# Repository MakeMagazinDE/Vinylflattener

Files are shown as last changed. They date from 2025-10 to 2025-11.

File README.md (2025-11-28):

GitHub Logo

Maker Media GmbH

***

# Der Vinylflattener

### Bauanleitung für eine Bügelmaschine für Schallplatten

Manchmal sind Schallplatten durch falsche Lagerung oder mangelhafte Herstellung krumm geworden. Mit Wärme und Druck lässt sich die Platte retten und sie liefert wieder ungetrübten Musikgenuss. Kommerzielle Maschinen sind jedoch sehr teuer. In der Make 7/25 zeigen wir, wie man für wenige hundert Euro eine funktionale Bügelmaschine mit sehr präziser Temperatursteuerung selber bauen kann. Hier findet ihr 3D-Druck-Dateien für diverse Teile, den Code für den ESP32 und Anweisungen, wie eine kleine Steuerplatine verdrahtet werden muss.

 

# UPDATE - Zugentlastung

### Während man die Zugentlastung am PC-Netzteil pragmatisch mit Kabelbindern am Gehäuse fixiert, brauchen die beiden Heizplatten eine stabilere Lösung.

Hierfür habe ich eine Kabeldurchführung mit Klemmwirkung, bestehend aus zwei 3d gedruckten Teilen konstruiert, welche dann noch durch sogenannte Streckenverbinder im Rahmen oben und unten integriert wird. Eventuell muss man die Madenschrauben der Streckenverbinder etwas mit der Feile kürzen, bis sie nicht mehr nach oben aus der Konstruktion herausragen.
Die entsprechenden STL-Dateien dazu haben wir auch hier hinterlegt.

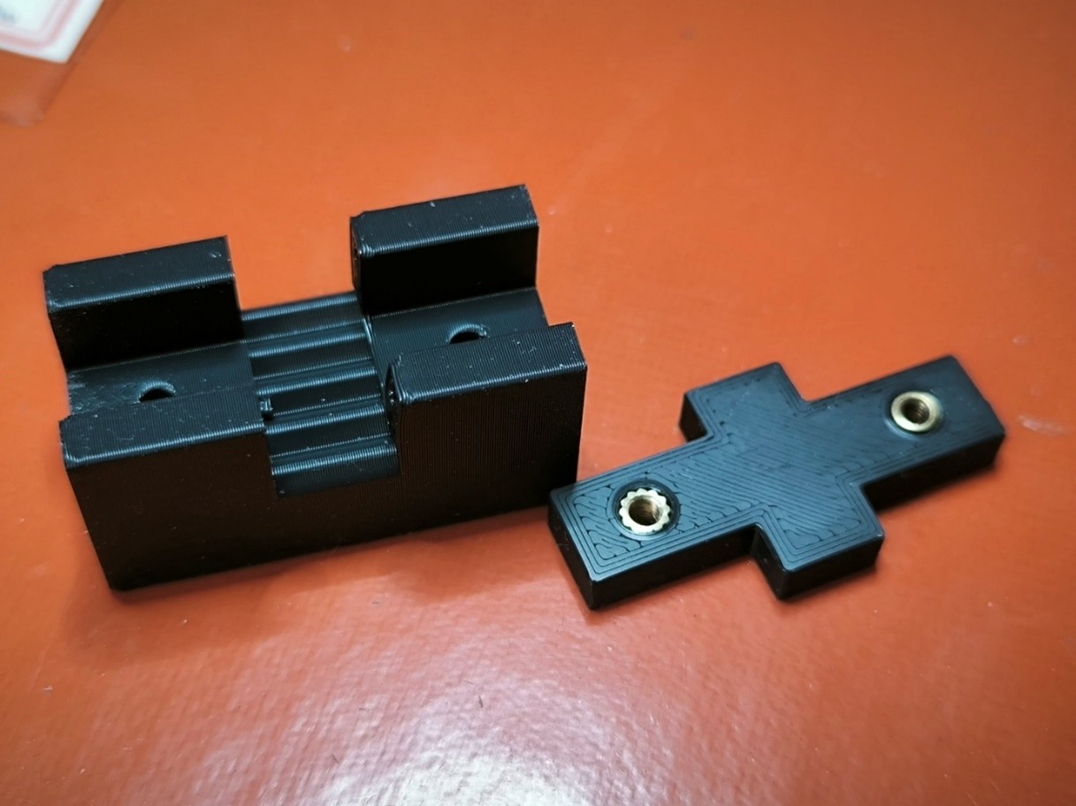
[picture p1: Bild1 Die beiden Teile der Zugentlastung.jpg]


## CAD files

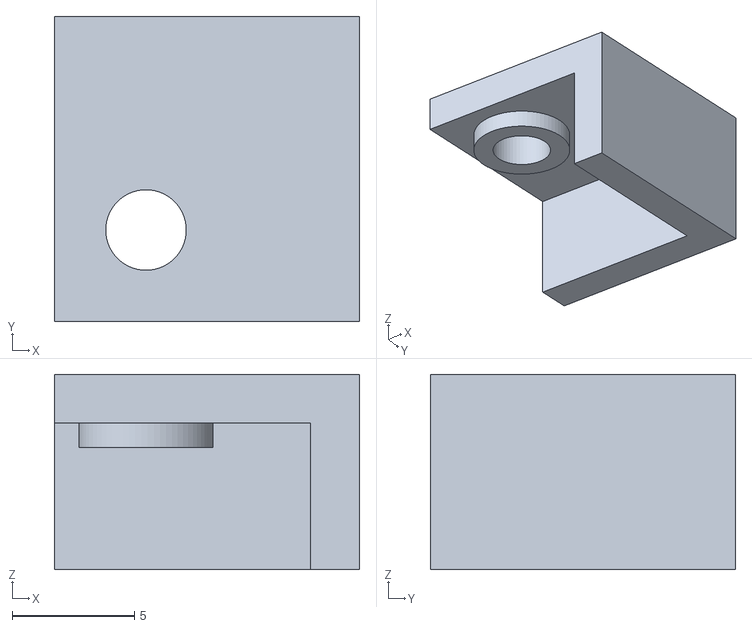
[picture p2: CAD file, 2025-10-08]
STL/VinylFlattener ESP Displayklammer v2.stl
12.5 x 12.5 x 8.00

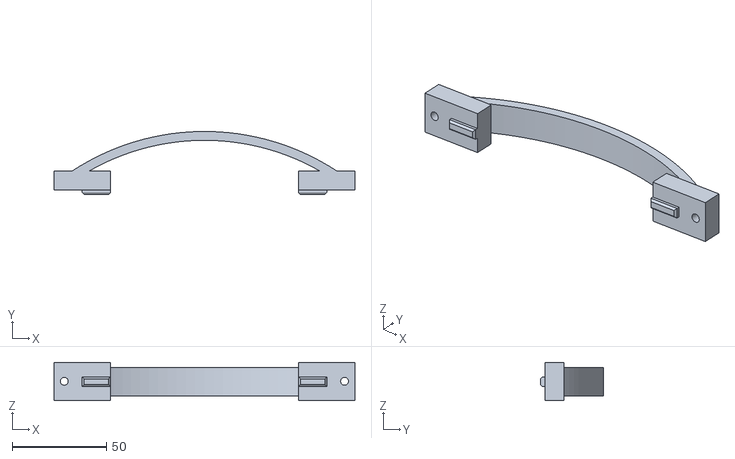
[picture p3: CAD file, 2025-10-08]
STL/Vinylflattener Griff_ASA v1.stl
160.0 x 33.5 x 20.2

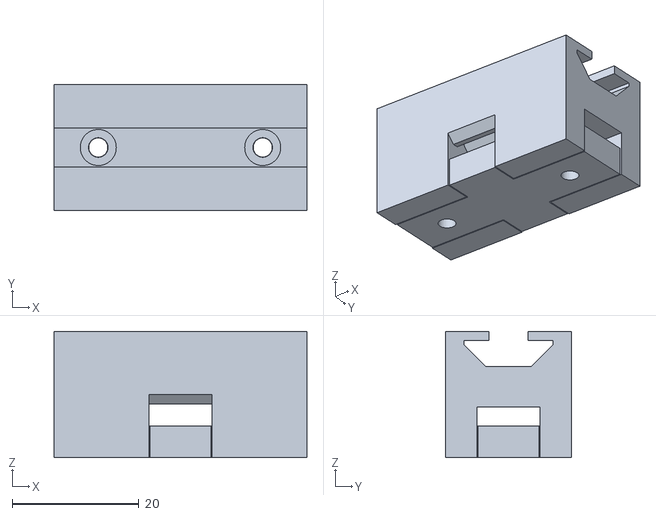
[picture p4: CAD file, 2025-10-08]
STL/Vinylflattener Kabeldurchführung v4.stl
40.0 x 20.0 x 20.0

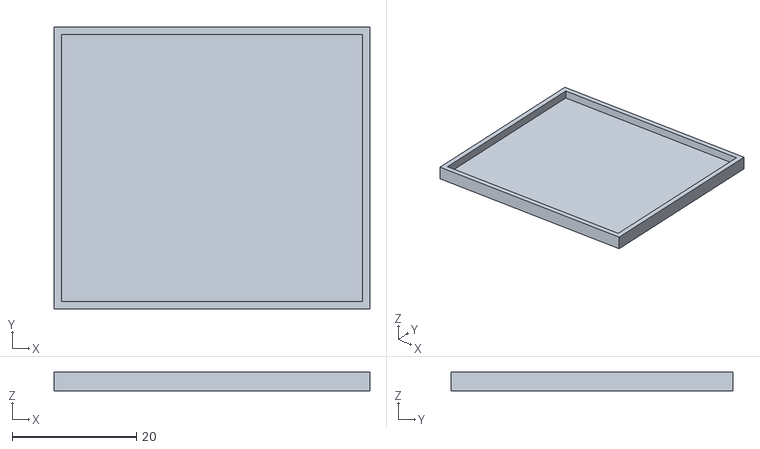
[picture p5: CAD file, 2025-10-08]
STL/Vinylflattener Platinenboden TPU v1.stl
50.9 x 45.4 x 3.00

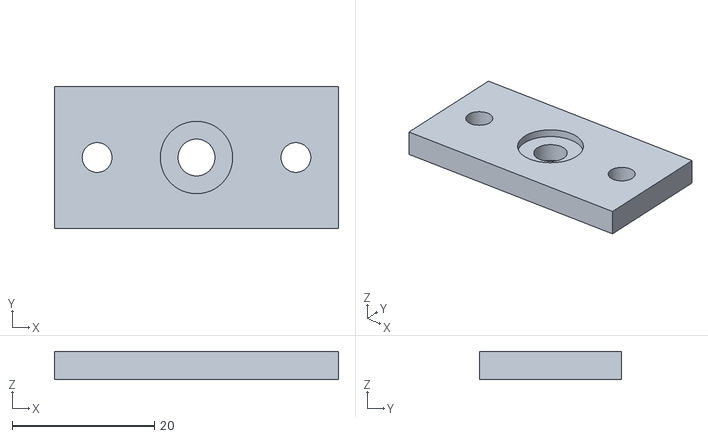
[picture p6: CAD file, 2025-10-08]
STL/Vinylflattener seitliche Scharnierhalterung v1.stl
40.0 x 20.0 x 4.00

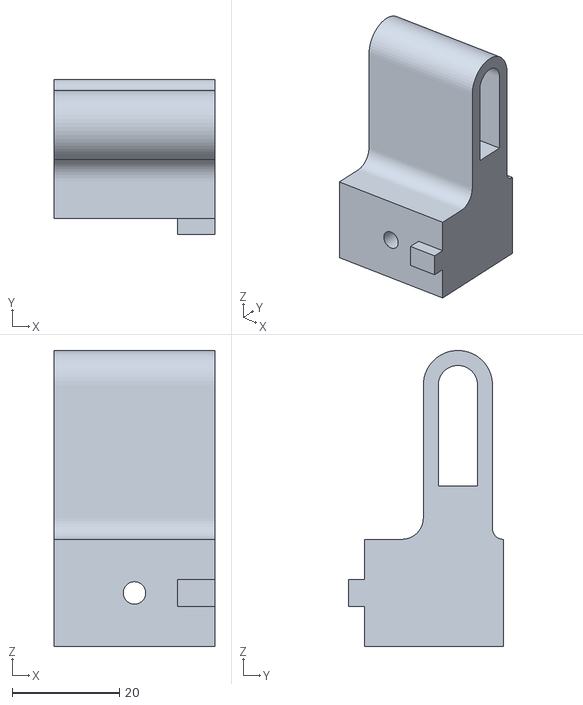
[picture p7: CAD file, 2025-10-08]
STL/Vinylflattener Scharnier unten.stl
30.0 x 29.0 x 55.2

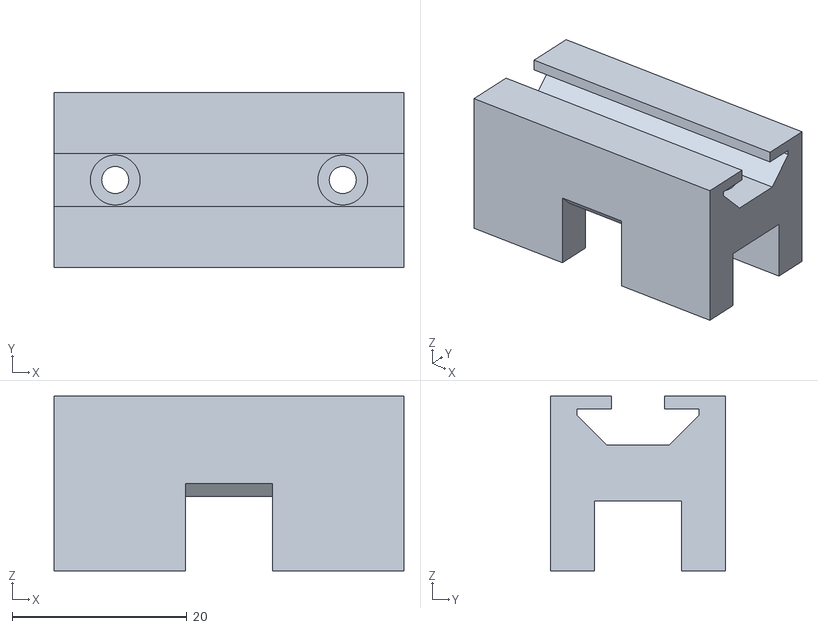
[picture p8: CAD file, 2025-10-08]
STL/Vinylflattener Kabeldurchführung v4 Oberteil.stl
40.0 x 20.0 x 20.0

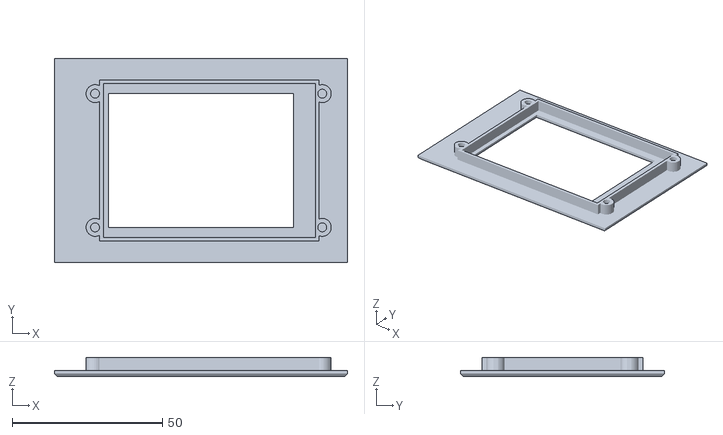
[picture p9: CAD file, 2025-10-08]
STL/VinylFlattener Einbaurahmen 2.8 Touch v4.stl
97.5 x 68.0 x 6.40

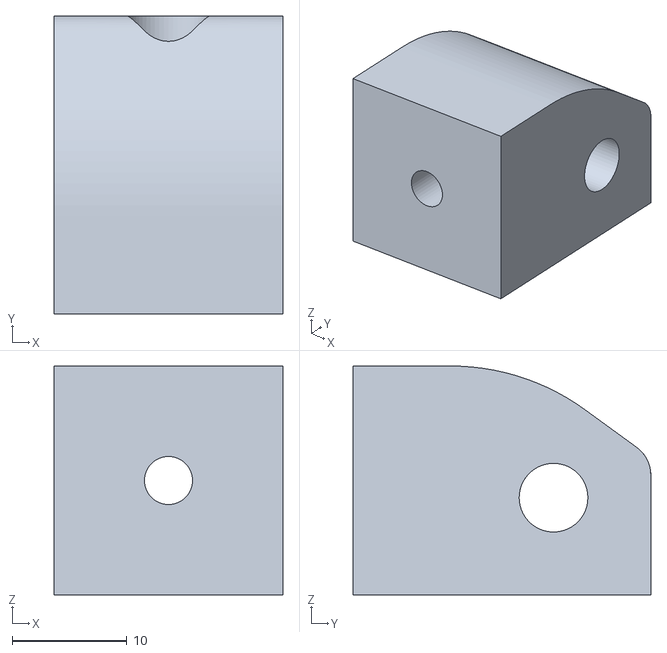
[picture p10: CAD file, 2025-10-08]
STL/Vinyflattener Scharnier oben v1.stl
20.0 x 26.0 x 20.0

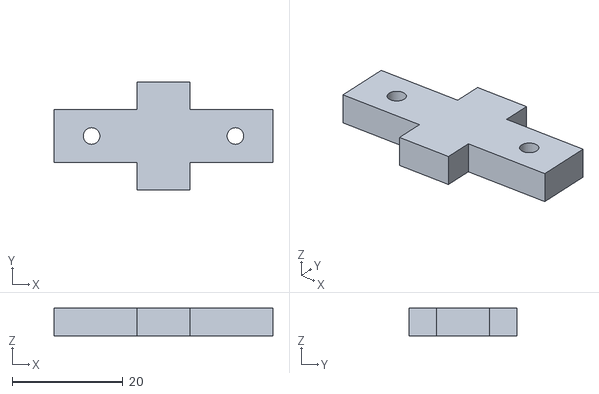
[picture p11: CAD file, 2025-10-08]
STL/Vinylflattener Kabeldurchführung v4 Unterteil.stl
39.6 x 19.6 x 5.00

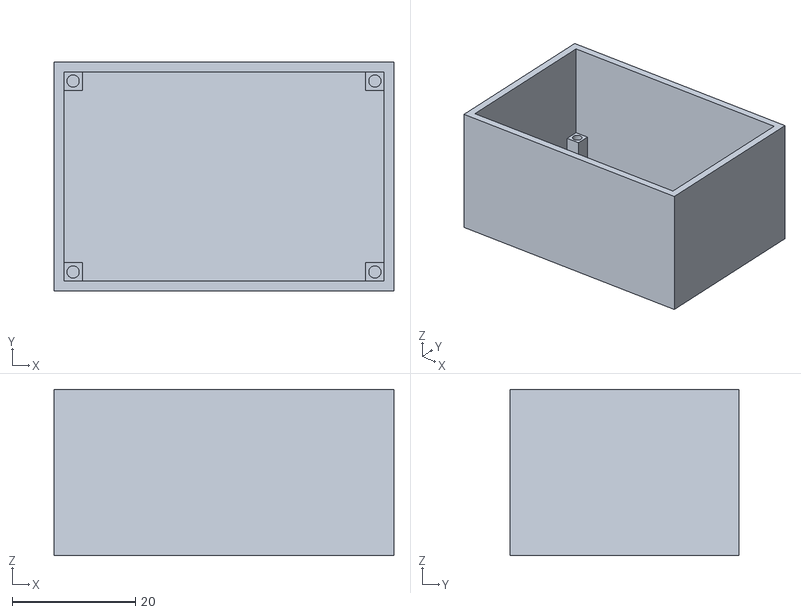
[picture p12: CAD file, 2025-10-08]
STL/Vinyflattener ESP Gehäuse v2 TPU.stl
55.2 x 37.2 x 27.0

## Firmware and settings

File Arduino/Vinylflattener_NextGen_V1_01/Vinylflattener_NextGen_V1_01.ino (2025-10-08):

/*
#diy #Vinylflattener, NextGen 
Version 1.01, 18.07.2025
@vincent05.bsky.social

Cleanup & Debug Ooption added

V1.01: MCP added

*/

//Libraries

#include <Arduino.h>
#include <Wire.h>
#include <FT6X36.h>
#include <TFT_eSPI.h>
#include <TaskScheduler.h>  // TaskScheduler Library

// uncomment for debug output
//#define DEBUG
//#define DEBUGSENSOR
//#define DEBUGMCP

// Heizungsregelung

#include <AutoPID.h>
#include <DallasTemperature.h>
#include <OneWire.h>

#define GFXFF 1
#define CF_RT24 &Roboto_Thin_24
#define CF_FSB12 &FreeSansBold12pt7b


//Temperaturregelung
#define TEMP_READ_DELAY 1000  //can only read digital temp sensor every ~750ms

//pid settings fuer Relaisbetieb
#define PULSEWIDTH 200   
//#define KP .12
//#define KI .0003
//#define KD 3
#define KP 0.09
#define KI 0.0002
#define KD 1.8


//GPIO Pins, die Pins fuer das TFT Display sind in der Datei User_Setup.h definiert

#define TEMP_SENSOR1_PIN 16
#define TEMP_SENSOR2_PIN 17
#define RELAIS1 5
#define RELAIS2 19
#define T_RST 27  // Touch Controller Reset Pin
#define T_INT 26  // Touch Controller Interrupt Pin

FT6X36 ts(&Wire, T_INT);  //Touch Controller Interruptpin (CTP_INT)
TFT_eSPI tft = TFT_eSPI();
// Button-Positionen und Größen
#define BUTTON_START_X 140
#define BUTTON_START_Y 200
#define BUTTON_START_W 100
#define BUTTON_START_H 50

#define BUTTON_STOP_X 20
#define BUTTON_STOP_Y 200
#define BUTTON_STOP_W 100
#define BUTTON_STOP_H 50

#define NAV_UP_X 300
#define NAV_UP_Y 40
#define NAV_DOWN_X 300
#define NAV_DOWN_Y 200

// Navigation button touch areas
#define NAV_UP_TOUCH_X 280
#define NAV_UP_TOUCH_Y 20
#define NAV_UP_TOUCH_W 40
#define NAV_UP_TOUCH_H 40

#define NAV_DOWN_TOUCH_X 280
#define NAV_DOWN_TOUCH_Y 180
#define NAV_DOWN_TOUCH_W 40
#define NAV_DOWN_TOUCH_H 40

// Slider-Bereiche
#define SLIDER_TEMP_X 20
#define SLIDER_TEMP_Y 80
#define SLIDER_TEMP_W 280
#define SLIDER_TEMP_H 20
#define SLIDER_TIME_X 20
#define SLIDER_TIME_Y 150
#define SLIDER_TIME_W 280
#define SLIDER_TIME_H 20

// Variablen Temperaturregelung
double targetTemperature = 55;    // Solltemperatur Startwert
double currentTemperature1 = 21;  // Isttemperatur 1
double currentTemperature2 = 22;  // Isttemperatur 2

double temperature1;
double temperature2;
double setPoint;
double tempThreshold = 0.8;  //Schwellwert für Abbruch bei Überhitzung (MCP Watchdog)

bool RelayControl1, RelayControl2;
double changeTemp1;
double changeTemp2;
double RampTime = 300;  // Zeitintervall für einen Durchlauf der Funktion TemperatureRamp (kleiner => genauer)
double RampUpdate = 0;  //Variable in der Funktion TemperatureRamp
double currentSetpoint = 10; //Variable in der Funktion TemperatureRamp
double powerupTemperature = 0;  //Variable in der Funktion TemperatureRamp
double powerUpFactor = 9;  // Zieltemperatur - powerUpFactor ergibt den Wert, bis zu dem das System ungeregelt aufheizt
double rampRate = 0.8;  //Variable in der Funktion TemperatureRamp, größer bedeutet schnelleres Aufheizen (default 0.5)
int pidTimeStep = 50;  // die Zeit, wie oft eine Neuberechnung von autoPID durchgeführt wird, sollte <= PULSEWIDTH sein

unsigned long lastTempUpdate1;  //tracks clock time of last temp1 update
unsigned long lastTempUpdate2;  //tracks clock time of last temp2 update
unsigned long Time;

// alle anderen Variablen
int timeSetting = 240;     // Zeiteinstellung (in Minuten), (Startwert)
int lastTargetTemp = -1;   // Zum Überprüfen, ob die Temperatur geändert wurde
int lastTimeSetting = -1;  // Zum Überprüfen, ob die Zeit geändert wurde
int countdownSeconds = 0;  // Anzeige basiert auf dieser Sekunde
int errorcount = 0;        // MCP Zähler
int stopcount = 0;         // MCP Zähler

// Slider-Bereiche definieren
const int tempMin = 48;   //Minimalwert Temperaturslider
const int tempMax = 70;   //Maximalwert Temperaturslider
const int timeMin = 1;    //Minimalwert Zeitslider
const int timeMax = 360;  //Maximalwert Zeitslider

// Letzte Slider-Positionen speichern (um alte Marker zu löschen)
int lastTempSliderPos = -1;
int lastTimeSliderPos = -1;

int old_x = 0;
int old_y = 0;


// Seitenwechsel
int currentPage = 1;
bool screenChanged = true;

// Timer Variablen
unsigned long timerStartMillis = 0;  // Speichert den Startzeitpunkt des Timers
unsigned long remainingMillis = 0;   // Speichert die verbleibende Zeit in Millisekunden
unsigned long lastUpdate = 0;        // Letzter Zeitpunkt, wo der Countdown aktualisiert wurde

// Timer läuft?
bool timerRunning = false;  // Flag, das angibt, ob der Timer läuft
bool timerExpired = false;  // Flag, das anzeigt, dass der Timer abgelaufen ist

//Laufzeitprüfung

unsigned long startTime = 0;
unsigned long endTime = 0;
unsigned long duration = 0;

//Temperatursteuerung initialisieren

OneWire oneWire1(TEMP_SENSOR1_PIN);
OneWire oneWire2(TEMP_SENSOR2_PIN);
DallasTemperature temperatureSensor1(&oneWire1);
DallasTemperature temperatureSensor2(&oneWire2);



//input/output variables passed by reference, so they are updated automatically
AutoPIDRelay myPID1(&temperature1, &setPoint, &RelayControl1, PULSEWIDTH, KP, KI, KD);
AutoPIDRelay myPID2(&temperature2, &setPoint, &RelayControl2, PULSEWIDTH, KP, KI, KD);

Scheduler runner;

//Funktionen zu den Tasks deklarieren
void updateRemainingMillis();   //Zeitbasis
void touchTaskCallback();       // Task für die Touch-Abfrage erstellen
void temperatureUpdateTask1();  //Abfrage Sensor 1
void temperatureUpdateTask2();  //Abfrage Sensor 2
void screenUpdateTask();        //Bildschirmaktualisierung während der Timer läuft
void countdownTickTask();       //Zeitanzeige mit eigener Zeitberechnung für den Timer
void masterControlProgram();    //Sicherheitstask zur Überwachung von max. Temp und Sensor Output

//Tasks
Task timerCalcTask(250, TASK_FOREVER, &updateRemainingMillis);
Task touchTask(5, TASK_FOREVER, &touchTaskCallback);
Task taskTempUpdate1(TEMP_READ_DELAY, TASK_FOREVER, &temperatureUpdateTask1);
Task taskTempUpdate2(TEMP_READ_DELAY, TASK_FOREVER, &temperatureUpdateTask2);
Task screenTask(20, TASK_FOREVER, &screenUpdateTask);
Task countdownTick(20, TASK_FOREVER, &countdownTickTask);
Task mcpTask(100, TASK_FOREVER, &masterControlProgram);

void countdownTickTask() {
  static int lastDisplayedSeconds = -1;

  if (timerRunning) {
    unsigned long elapsed = millis() - timerStartMillis;
    int newCountdownSeconds = (timeSetting * 60) - (elapsed / 1000);

    // Timerende prüfen
    if (newCountdownSeconds <= 0) {
      countdownSeconds = 0;
      timerRunning = false;
      timerExpired = true;
      stopAll();
    } else {
      countdownSeconds = newCountdownSeconds;
    }

    // Nur anzeigen, wenn sich die Sekunde geändert hat
    if (countdownSeconds != lastDisplayedSeconds) {
      lastDisplayedSeconds = countdownSeconds;
      updateCountdown();  // Anzeige aktualisieren
    }
  }
}


void updateRemainingMillis() {
  if (timerRunning && !timerExpired) {
    unsigned long timerMillis = millis();
    remainingMillis = (timeSetting * 60 * 1000) - (timerMillis - timerStartMillis);

    if ((remainingMillis <= 0) || (remainingMillis > (timeSetting * 60 * 1000))) {
      remainingMillis = 0;
      timerRunning = false;
      timerExpired = true;
#ifdef DEBUG
      Serial.println("Timer abgelaufen!");
#endif
      stopAll();
    }
  }
}

void handleNavigation(TPoint p) {
  int oldPage = currentPage;

  if (p.x > NAV_UP_TOUCH_X && p.x < NAV_UP_TOUCH_X + NAV_UP_TOUCH_W && p.y > NAV_UP_TOUCH_Y && p.y < NAV_UP_TOUCH_Y + NAV_UP_TOUCH_H) {
    currentPage++;
    if (currentPage > 3) currentPage = 1;
  } else if (p.x > NAV_DOWN_TOUCH_X && p.x < NAV_DOWN_TOUCH_X + NAV_DOWN_TOUCH_W && p.y > NAV_DOWN_TOUCH_Y && p.y < NAV_DOWN_TOUCH_Y + NAV_DOWN_TOUCH_H) {
    currentPage--;
    if (currentPage < 1) currentPage = 3;
  }

  if (oldPage != currentPage) {
    screenChanged = true;
#ifdef DEBUG
    Serial.print("Switching to page: ");
    Serial.println(currentPage);
#endif
  }
}

void processTouch(TPoint p, TEvent e) {

  // if ((e == TEvent::Tap) || (e == TEvent::TouchMove)) {
  if (e != TEvent::Tap && e != TEvent::DragStart && e != TEvent::DragMove && e != TEvent::DragEnd)
    return;

  // Umrechnen der X- und Y-Koordinaten
  int new_x = 320 - p.y;  // 320 - Y_Touch
  int new_y = p.x;        // X_Touch

  p.x = new_x;
  p.y = new_y;
  if ((old_x == new_x) && (old_y == new_y))
    return;  //deBouncing durch Abbruch bei identischen Werten für x und Y

  old_x = new_x;
  old_y = new_y;
#ifdef DEBUG
  Serial.print("Tap detected at X: ");
  Serial.print(p.x);
  Serial.print(" Y: ");
  Serial.println(p.y);
#endif
  switch (currentPage) {
    case 1:
      if (p.x > BUTTON_START_X && p.x < BUTTON_START_X + BUTTON_START_W && p.y > BUTTON_START_Y && p.y < BUTTON_START_Y + BUTTON_START_H) {
#ifdef DEBUG
        Serial.println(F("Start Button pressed"));
#endif
        if (!timerRunning) {
          timerRunning = true;
          timerStartMillis = millis();
          remainingMillis = timeSetting * 60 * 1000;
          countdownSeconds = timeSetting * 60;  // ← neue Anzeige-Zeit in Sekunden
          timerExpired = false;
        }
      }

      if (p.x > BUTTON_STOP_X && p.x < BUTTON_STOP_X + BUTTON_STOP_W && p.y > BUTTON_STOP_Y && p.y < BUTTON_STOP_Y + BUTTON_STOP_H) {
#ifdef DEBUG
        Serial.println(F("Stop Button pressed"));
#endif
        stopAll();
      }
      break;
    case 2:
#ifdef DEBUG
      Serial.println(F("Touchscreen 2"));
      Serial.print(p.x);
      Serial.print(" Y: ");
      Serial.println(p.y);
#endif
      // Slider-Berührung
      if (p.x > SLIDER_TEMP_X && p.x < SLIDER_TEMP_X + SLIDER_TEMP_W && p.y > SLIDER_TEMP_Y && p.y < SLIDER_TEMP_Y + SLIDER_TEMP_H) {
        targetTemperature = map(p.x, SLIDER_TEMP_X, SLIDER_TEMP_X + SLIDER_TEMP_W, tempMin, tempMax);
        drawSlider(SLIDER_TEMP_X, SLIDER_TEMP_Y, SLIDER_TEMP_W, targetTemperature, tempMin, tempMax, TFT_RED, lastTempSliderPos);
#ifdef DEBUG
        Serial.print(F("Temperature set to: "));
        Serial.println(targetTemperature);
#endif
      }
      if (p.x > SLIDER_TIME_X && p.x < SLIDER_TIME_X + SLIDER_TIME_W && p.y > SLIDER_TIME_Y && p.y < SLIDER_TIME_Y + SLIDER_TIME_H) {
        timeSetting = map(p.x, SLIDER_TIME_X, SLIDER_TIME_X + SLIDER_TIME_W, timeMin, timeMax);
        drawSlider(SLIDER_TIME_X, SLIDER_TIME_Y, SLIDER_TIME_W, timeSetting, timeMin, timeMax, TFT_BLUE, lastTimeSliderPos);
#ifdef DEBUG
        Serial.print(F("Time set to: "));
        Serial.println(timeSetting);
#endif
      }
      break;
    case 3:
      //Touchscreen 3;
#ifdef DEBUG
      Serial.println(F("Touchscreen 3"));
      Serial.print(p.x);
      Serial.print(" Y: ");
      Serial.println(p.y);
#endif
      break;
  }
  handleNavigation(p);

  //}
}


void updateScreen() {
  if (!screenChanged) return;

  tft.fillScreen(TFT_BLACK);  // Clear screen
  //tft.setCursor(50, 50);
  //tft.setTextColor(TFT_WHITE);

  switch (currentPage) {
    case 1:
      //tft.print("Screen 1");
      setupScreen1();
      break;
    case 2:
      //tft.print("Screen 2");
      setupScreen2();
      break;
    case 3:
      //tft.print("Screen 3");
      setupScreen3();
      break;
  }

  drawNavigationArrows();
  screenChanged = false;
}

void drawNavigationArrows() {
  // Oben (nächste Seite)
  tft.fillTriangle(NAV_UP_X, NAV_UP_Y, NAV_UP_X - 10, NAV_UP_Y - 20, NAV_UP_X - 20, NAV_UP_Y, TFT_WHITE);

  // Unten (vorherige Seite)
  tft.fillTriangle(NAV_DOWN_X, NAV_DOWN_Y, NAV_DOWN_X - 10, NAV_DOWN_Y + 20, NAV_DOWN_X - 20, NAV_DOWN_Y, TFT_WHITE);
}

void drawStartStopButtons() {
  // Start-Button (rechts unten)
  tft.fillRect(BUTTON_START_X, BUTTON_START_Y, BUTTON_START_W, BUTTON_START_H, TFT_GREEN);
  tft.setTextColor(TFT_WHITE);
  tft.setCursor(BUTTON_START_X + 14, BUTTON_START_Y + 28);
  tft.print("START");

  // Stop-Button (links unten)
  tft.fillRect(BUTTON_STOP_X, BUTTON_STOP_Y, BUTTON_STOP_W, BUTTON_STOP_H, TFT_RED);
  tft.setTextColor(TFT_WHITE);
  tft.setCursor(BUTTON_STOP_X + 16, BUTTON_STOP_Y + 28);
  tft.print("STOP");
}

void setupScreen1() {

  // Fülle den Bildschirm mit Hintergrundfarbe
  tft.fillScreen(TFT_BLACK);

  // Zeichne Textzeilen
  tft.setTextColor(TFT_WHITE, TFT_BLACK);
  tft.setFreeFont(CF_RT24);  // Setzt den Font auf Roboto Thin 24

  tft.setCursor(20, 20);
  tft.print("Ist-Temp 1: ");
  //tft.print(currentTemperature1);
  tft.print(temperature1);
  tft.print(" C");

  tft.setCursor(20, 50);
  tft.print("Ist-Temp 2: ");
  //tft.print(currentTemperature2);
  tft.print(temperature2);
  tft.print(" C");

  tft.setCursor(20, 80);
  tft.print("Soll-Temp:  ");
  tft.print(targetTemperature);
  tft.print(" C");

  if (!timerRunning) {
    // } else {
    tft.setCursor(20, 110);
    tft.print("Restzeit:   ");
    tft.print(timeSetting);
    tft.print(":00");
    tft.print(" Min");
  }

  // Start- und Stop-Buttons zeichnen
  drawStartStopButtons();
  drawNavigationArrows();
}

void setupScreen2() {
  // Seite 2: Solltemperatur und Zeit einstellen
  tft.fillScreen(TFT_BLACK);
  tft.setFreeFont(CF_RT24);  // Setzt den Font auf Roboto Thin 24

  tft.setCursor(50, 50);
  tft.setTextColor(TFT_WHITE);
  tft.print("Soll-Temp: ");
  tft.print(targetTemperature);
  tft.print(" C");

  tft.setCursor(50, 120);
  tft.setTextColor(TFT_WHITE);
  tft.print("Zeit: ");
  tft.print(timeSetting);
  tft.print(" Min");

  // Slider für Temperatur zeichnen
  drawSlider(20, 80, 280, targetTemperature, tempMin, tempMax, TFT_RED, lastTempSliderPos);

  // Slider für Zeit zeichnen
  drawSlider(20, 150, 280, timeSetting, timeMin, timeMax, TFT_BLUE, lastTimeSliderPos);



  drawNavigationArrows();
}
// Slider zeichnen
void drawSlider(int x, int y, int w, int value, int minVal, int maxVal, uint16_t color, int &lastPos) {
  tft.drawRect(x, y, w, 10, TFT_WHITE);

  int sliderPos = map(value, minVal, maxVal, x, x + w);

  if (lastPos != -1 && lastPos != sliderPos) {
    tft.fillRect(lastPos - 5, y - 5, 10, 20, TFT_BLACK);
  }

  tft.fillRect(sliderPos - 5, y - 5, 10, 20, color);

  lastPos = sliderPos;
}

void setupScreen3() {

  // Fülle den Bildschirm mit Hintergrundfarbe
  tft.fillScreen(TFT_DARKGREEN);
  tft.setTextColor(TFT_LIGHTGREY);
  tft.setFreeFont(CF_RT24);  // Setzt den Font auf Roboto Thin 24

  tft.setCursor(30, 50);
  //tft.setTextColor(TFT_WHITE);
  tft.print("#diy #Vinylflattener");
  tft.setCursor(30, 90);
  tft.print("NextGen V1.0, 2025");
  tft.setCursor(30, 130);
  tft.print("contact:");
  tft.setCursor(30, 170);
  tft.print("@vincent05.bsky.social");

  drawNavigationArrows();  // Zeichne Navigationspfeile
}

void screenUpdateTask() {

  if (currentPage == 1) {
    unsigned long updateMillis = millis();
    if (updateMillis - lastUpdate >= 500) {
      if ((abs(changeTemp1) >= 0.06) || (abs(changeTemp2) >= 0.06)) {
        tft.fillRect(150, 0, 120, 24, TFT_BLACK);
        tft.setCursor(20, 20);
        tft.setTextColor(TFT_WHITE);
        tft.print("Ist-Temp 1: ");
        //tft.print(currentTemperature1); //Darstellung der Sensordaten
        tft.print(temperature1);  //fehlerbereinigte Darstellung
        tft.print(" C");

        tft.fillRect(150, 30, 120, 24, TFT_BLACK);
        tft.setCursor(20, 50);
        tft.setTextColor(TFT_WHITE);
        tft.print("Ist-Temp 2: ");
        //tft.print(currentTemperature2); //fehlerbereinigte Darstellung
        tft.print(temperature2);  //fehlerbereinigte Darstellung
        tft.print(" C");
      }

      lastUpdate = updateMillis;
    }
  } else if (currentPage == 2) {
    updateControlPage();
  }
}
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
void loop() {

  endTime = millis();

  runner.execute();  // Scheduler steuert die Tasks

  //Temperaturregelung
  Time = millis();
  if (timerRunning && !timerExpired) {
    TemperatureRamp();

    myPID1.run();  //call every loop, updates automatically at certain time interval
    myPID2.run();  //call every loop, updates automatically at certain time interval
  }
  if (RelayControl1 != 0) {
    digitalWrite(RELAIS1, HIGH);
  } else {
    digitalWrite(RELAIS1, LOW);
  }
  if (RelayControl2 != 0) {
    digitalWrite(RELAIS2, HIGH);
  } else {
    digitalWrite(RELAIS2, LOW);
  }

  updateScreen();  // Bildschirm Update falls notwendig

  duration = endTime - startTime;
  if (duration > 1) {
#ifdef DEBUG
    Serial.print("Laufzeit: ");
    Serial.println(duration);
#endif
  }
  startTime = millis();
}

void touchTaskCallback() {
  ts.loop();  // Touch-Abfrage ausführen // Hier kannst du weitere Aktionen ausführen, wenn ein Touch-Event erkannt wird
  if (ts.touched()) {
    //  unsigned char result = ts.touched();
    unsigned char result = ts.getCachedTouches();

#ifdef DEBUG
    Serial.println("Touch detected");
    Serial.println(result);
#endif
  }
}

void temperatureUpdateTask1() {

  if ((millis() - lastTempUpdate1) > TEMP_READ_DELAY) {
    temperature1 = temperatureSensor1.getTempCByIndex(0);  //get temp reading
    lastTempUpdate1 = millis();
    temperatureSensor1.requestTemperatures();  //request reading for next time
    changeTemp1 = currentTemperature1 - temperature1;
    currentTemperature1 = temperature1;
    if (currentTemperature1 < 0) {  //errorhandling, wenn der Sensor -127 zurück gibt
      temperature1 = targetTemperature;
#ifdef DEBUGSENSOR
      Serial.println("error reading Temperature Sensor 1");
#endif
    }
  }
}

void temperatureUpdateTask2() {
  if ((millis() - lastTempUpdate2) > TEMP_READ_DELAY) {
    temperature2 = temperatureSensor2.getTempCByIndex(0);  //get temp reading
    lastTempUpdate2 = millis();
    temperatureSensor2.requestTemperatures();  //request reading for next time
    changeTemp2 = currentTemperature2 - temperature2;
    currentTemperature2 = temperature2;
    if (currentTemperature2 < 0) {  //errorhandling, wenn der Sensor -127 zurück gibt
      temperature2 = targetTemperature;
#ifdef DEBUGSENSOR
      Serial.println("error reading Temperature Sensor 2");
#endif
    }
  }
}

// Sicherstellen, dass die Temperatur in Richtung Zielwert nicht zu stark ansteigt
void TemperatureRamp() {
  if ((millis() - RampUpdate) > RampTime) {
    powerupTemperature = targetTemperature - powerUpFactor;
    RampUpdate = millis();
    if (!((temperature1 < powerupTemperature) && (temperature2 < powerupTemperature))) {
      if (temperature1 < temperature2) {
        currentSetpoint = temperature1;
      } else {
        currentSetpoint = temperature2;
      }

      if (currentSetpoint < targetTemperature) {
        currentSetpoint += rampRate;
        setPoint = currentSetpoint;
        if (currentSetpoint > targetTemperature) {
          currentSetpoint = targetTemperature;
          setPoint = currentSetpoint;
        }
      }
    } else {
      setPoint = targetTemperature;
#ifdef DEBUGSENSOR
      Serial.println("Heating!!!");
#endif
    }
#ifdef DEBUGSENSOR
    Serial.print("Temperatur 1: ");
    Serial.println(temperature1);
    Serial.print("Temperatur 2: ");
    Serial.println(temperature2);
    Serial.print("currentSetPoint: ");
    Serial.println(currentSetpoint);
    Serial.print("SetPoint: ");
    Serial.println(setPoint);
    Serial.print("powerUpTemperature: ");
    Serial.println(powerupTemperature);
    Serial.print("powerUpFactor: ");
    Serial.println(powerUpFactor);
#endif
  }
}

void masterControlProgram() {

  double stopTemperature = targetTemperature + tempThreshold;
  if ((temperature1 > stopTemperature) || (temperature2 > stopTemperature)) {
#ifdef DEBUGMCP
    Serial.print("Temperatur zu hoch: ");
    Serial.println(stopTemperature);
    Serial.print("Zieltemperatur: ");
    Serial.print(targetTemperature);
    Serial.print(" Schwellwert: ");
    Serial.println(tempThreshold);
#endif
    if (timerRunning) {  //nur auf Temperaturfehler reagieren, wenn der Timer läuft
      stopcount++;
      if ((stopcount > 2) && (stopcount < 5)) {
        String alarmtext = "      Ueberhitzung";
        errorScreen(alarmtext);
        stopError();
      }
    }
  } else if (currentTemperature1 < 0) {  //Temperatursensor 1 prüfen
    errorcount++;                        //Fehlerzähler um 1 erhöhen
#ifdef DEBUGMCP
    Serial.print("Fehler Sensor 1 entdeckt: ");
    Serial.println(errorcount);
#endif
    if (errorcount > 100) {  //erst verzögert reagieren, um Einzelfehler zu ignorieren
#ifdef DEBUGMCP
      Serial.print("Sensor 1 ausgefallen ");
      Serial.println(currentTemperature1);
#endif
      stopcount++;
      if ((stopcount > 2) && (stopcount < 5)) {
        String alarmtext = "Sensor 1 ausgefallen ";
        errorScreen(alarmtext);
      }
    }
  } else if (currentTemperature2 < 0) {  //Temperatursensor 2 prüfen
    errorcount++;                        //Fehlerzähler um 1 erhöhen
#ifdef DEBUGMCP
    Serial.print("Fehler Sensor 2 entdeckt: ");
    Serial.println(errorcount);
#endif
    if (errorcount > 100) {  //erst verzögert reagieren, um Einzelfehler zu ignorieren
#ifdef DEBUGMCP
      Serial.print("Sensor 2 ausgefallen ");
      Serial.println(currentTemperature2);
#endif
      stopcount++;
      if ((stopcount > 2) && (stopcount < 5)) {
        String alarmtext = "Sensor 2 ausgefallen ";
        errorScreen(alarmtext);
      }
    }
  } else {
    errorcount = 0;
    stopcount = 0;
  }
}
void errorScreen(String outText) {
  tft.fillScreen(TFT_ORANGE);
  tft.setFreeFont(CF_FSB12);  // Setzt den Font auf Roboto Thin 24

  tft.setCursor(28, 50);
  tft.setTextColor(TFT_BLUE);
  tft.print("!!! SYSTEM HALTED !!!");
  tft.setCursor(35, 120);
  tft.print(outText);
  stopError();  // alle Funktionstasks anhalten
}

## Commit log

2025-10-08 bulk upload of files and folders
    [Vinyflattener ESP Gehäuse v2 TPU.stl, Vinyflattener Scharnier oben v1.stl, Vinyflattener Verdrahtung.xlsx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]
2025-11-28 Update README with cable strain relief instructions
    Added section on cable strain relief for heating plates.
